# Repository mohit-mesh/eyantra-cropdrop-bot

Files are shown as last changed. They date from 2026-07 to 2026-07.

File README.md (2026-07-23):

# CropDrop Bot 🚜📦
**Autonomous Logistics System for the e-Yantra International Robotics Competition**

WhatsApp Image 2026-07-23 at 11 56 01

## 🏆 Project Overview
This repository contains the hardware designs and software stack for the "CropDrop Bot," an autonomous logistics robot. Developed for the **international e-Yantra Robotics Competition**, our system was engineered to navigate complex environments, manage payload logistics, and execute precise line-following tasks. 

Out of over 1,000 participating teams globally, our project secured a place among the **Top 20 ranked teams**.
The robot bridges low-level precision hardware with high-level autonomous decision-making. 

### Hardware Specifications
* **Microcontroller:** STM32 F103RB (ARM Cortex-M3) acting as the powerhouse for low-level execution and sensor polling.
* **Chassis & Mechanical:** Custom-modeled in Autodesk Fusion 360. The physical bot was specifically designed with a low center of gravity to ensure stability during dynamic movements and payload handling.

### Software Stack
* **Languages:** Python, C++
* **Control Systems:** We implemented a hybrid control approach using **PID controllers** combined with **Reinforcement Learning** to achieve smooth, adaptable, and highly accurate line-following behaviors under varying conditions.

## 📁 Repository Structure
```text
├── cad/                 # Fusion 360 STEP files and chassis renders
├── firmware/            # STM32 F103RB C++ source code and libraries
├── docs/                # Schematics, competition reports, and media
└── README.md

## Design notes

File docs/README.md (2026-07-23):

# 📚 Project Documentation & Media

This directory serves as the central hub for all non-code assets related to the CropDrop Bot. It includes system architecture diagrams, wiring schematics, and the progression of deliverables submitted for the e-Yantra Robotics Competition.

## 🏆 Task Progression & Video Demonstrations

The e-Yantra competition was structured as a rigorous, multi-stage evaluation. Below is the chronological breakdown of our submissions, including the specific objectives and video evidence for each stage.

### Phase 1: Simulation & Basic Control
| Task | Objective | Deliverables / Media Links |
| :--- | :--- | :--- |
| **Task 0** | Introduction to CoppeliaSim environment and basic API interactions. |
| **Task 1A** | Basic locomotion and kinematics implementation in simulation. | [Watch Video](https://youtu.be/E3lrXw1rDbM) |
| **Task 1B** | Sensor integration (vision/proximity) within the CoppeliaSim scene. | [Watch Video](https://youtu.be/_9AlKNXZCRw) |

### Phase 2: Autonomous Navigation (Simulation)
| Task | Objective | Deliverables / Media Links |
| :--- | :--- | :--- |
| **Task 2A** | Implementation of path planning algorithms in simulation. | [Watch Video](https://youtu.be/VgObchYK7ao) |
| **Task 2B** | Advanced obstacle avoidance and dynamic path replanning. | [Watch Video](https://youtu.be/pBu2Rf4UkDo) |

### Phase 3: Hardware Assembly & Setup
| Task | Objective | Deliverables / Media Links |
| :--- | :--- | :--- |
| **Task 3A** | Physical arena preparation (Flex printing and spatial calibration). | (Arena
 ) |
| **Task 3B** | Complete physical assembly of the robot (chassis, motors, sensors). | (Bot
 ) |
| **Task 3C** | Hardware-in-the-loop testing and initial motor driver calibration. | [Watch Video](https://youtube.com/shorts/ha-Rx2h62M0?feature=share) |

### Phase 4: Physical Implementation & Tuning
| Task | Objective | Deliverables / Media Links |
| :--- | :--- | :--- |
| **Task 4A** | Basic line following using IR sensor arrays (PID control). | [Watch Video](https://youtube.com/shorts/gG-tcj1-eJs?feature=share) |
| **Task 4B** | Reinforcement Learning implementation for high-speed, stable line tracking. | [Watch Video](https://youtube.com/shorts/Vpe7SxNsrb0?feature=share) |
| **Task 4C** | Integration of payload actuation (servo manipulation) with locomotion. | [Watch Video](https://youtube.com/shorts/bxdxO41b7do?feature=share) |

### Phase 5: System Integration & Optimization
| Task | Objective | Deliverables / Media Links |
| :--- | :--- | :--- |
| **Task 5A** | Establishing reliable ROS 2 to STM32 serial communication. | [Watch Video](https://youtube.com/shorts/iJJi3lMqJCQ?feature=share) |
| **Task 5B** | Integration of high-level task logic with low-level physical control. | [Watch Video](https://youtube.com/shorts/guk6uJNxQB8?feature=share) |

### Phase 6: The Grand Finale
| Task | Objective | Deliverables / Media Links |
| :--- | :--- | :--- |
| **Task 6** | **Final Theme Run:** Complete, autonomous execution of the entire logistics challenge. | [Watch Final Run Video 🌟](https://youtu.be/hnjJy23xpFI) |
| **Bonus Task** | Implementation of advanced optimizations (e.g., faster route planning and extended payload capacity) for extra points. | [Watch Bonus Run Video 🚀](https://youtu.be/7lcOlLQVplg) |

---

*Note: All corresponding source code for these tasks can be found in the respective task folders within the main repository.*

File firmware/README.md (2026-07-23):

# 💻 Firmware & Low-Level Control

This directory contains the embedded C/C++ firmware developed for the STM32 F103RB microcontroller, which acts as the low-level hardware interface for the CropDrop Bot.

The firmware is responsible for executing real-time control loops, processing raw sensor data, and safely actuating the mechanical systems based on high-level commands from the ROS 2 stack.

## ⚙️ Core Features & Capabilities

The codebase utilizes the **STM32 HAL (Hardware Abstraction Layer)** to manage the following sub-systems:

*   **Closed-Loop Locomotion:** Implements a real-time **PID control loop** for high-speed, accurate line following, utilizing fast-polling ADC reads from the IR sensor arrays.
*   **Payload Actuation:** Manages precise PWM signal generation (via hardware Timers) to control the servo motors responsible for the payload dropping mechanism.
*   **ROS 2 Serial Bridge:** Establishes robust, non-blocking UART communication to receive velocity/navigation commands from the main compute node and report back current hardware states.
*   **State Machine Architecture:** The main execution loop is structured as a non-blocking state machine, ensuring deterministic response times for critical hardware interrupts.

## 📂 Directory Structure

*   **`Core/Src/`**: Contains the main application logic (`main.c`), interrupt service routines (`stm32f1xx_it.c`), and hardware initialization functions.
*   **`Core/Inc/`**: Contains the corresponding header files.
*   **`.ioc File`**: The STM32CubeMX configuration file detailing the clock tree, pinout (GPIO, UART, I2C), and timer configurations.

> **Note to Reviewers:** The core logic, including the PID implementation and serial parsing, can be found in `Core/Src/main.c`.

## 🛠️ Build & Flash Instructions

This project is configured for use with **STM32CubeIDE**.

1.  Open **STM32CubeIDE**.
2.  Select `File` > `Open Projects from File System...`
3.  Navigate to this folder and click Finish to import the project.
4.  Click the **Build (Hammer)** icon to compile the `.elf` and `.bin` files.
5.  Connect your ST-Link to the STM32 F103RB board.
6.  Click the **Debug/Run** icon to flash the firmware directly to the microcontroller.

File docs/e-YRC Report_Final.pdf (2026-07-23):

# e-Yantra Robotics Competition 2025-26

## Technical Project Report

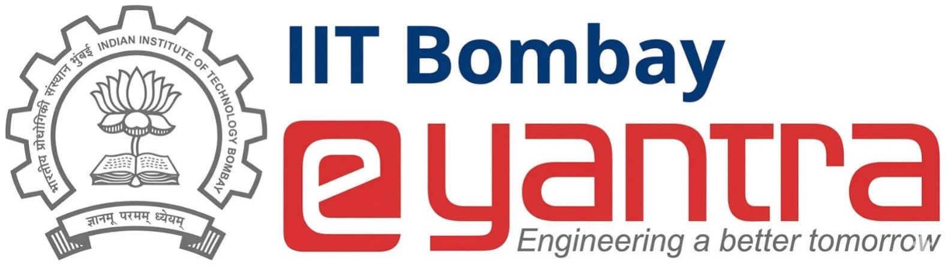
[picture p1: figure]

### Theme: Crop Drop Bot

### Institution: Zeal College of Engineering and Research

## Team Members

### Mohit (Team Lead) Sanyog Dahotre Aaryan Nikam

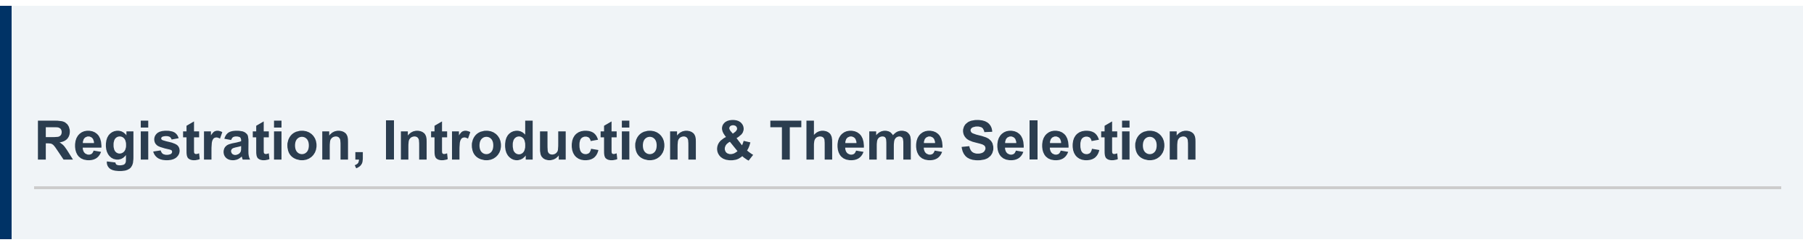
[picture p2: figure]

### 1.1 Introduction

The e-Yantra Robotics Competition (eYRC) is a flagship initiative by IIT Bombay. It provides a unique platform for engineering students to implement theory into practice through a project-based learning approach. This report documents the technical journey of the team from Zeal College of Engineering and Research in the 2025-26 edition of eYRC.

### 1.2 Team Formation

Our team was formed with a shared passion for robotics and
automation. Led by Mohit, who took on the responsibility of the
College Group Team Lead, the team comprises Sanyog Dahotre and

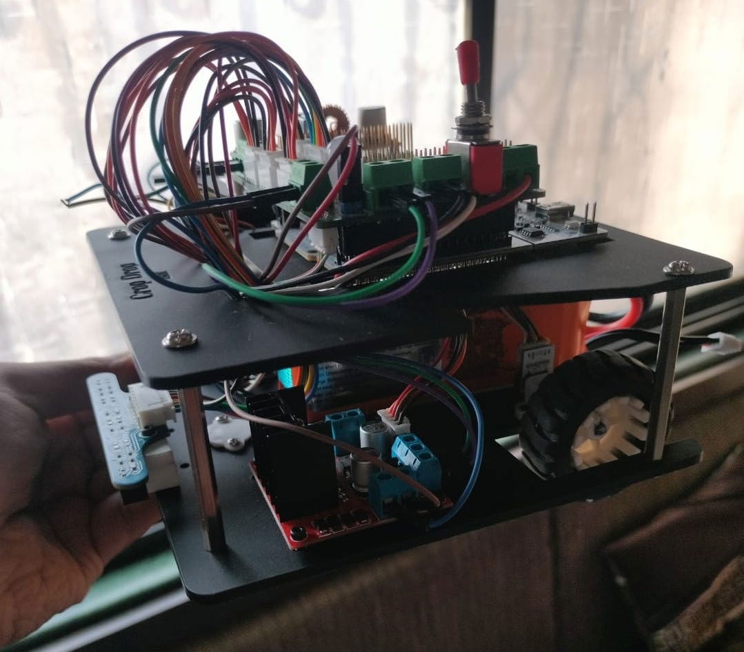
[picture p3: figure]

Aaryan Nikam. Each member brought a distinct skill set to the table, ranging from embedded systems and hardware assembly to algorithmic problem solving and simulation.

### 1.3 Theme Selection: Crop Drop Bot

Among the various themes offered in eYRC 2025-26, our team unanimously selected the "Crop Drop Bot" theme. This theme focuses on autonomous navigation and service roboticsin an agricultural context. The challenge involves designing a robot capable of traversing a greenhouse environment, identifying service zones, and performing pickand-place operations to manage crops.

We chose this theme for several strategic reasons:
Relevance: Agricultural automation is a burgeoning field with significant real-world impact. Complexity Balance: It offered a balanced mix of precision line following, complex decision-making algorithms, and mechanical manipulation.
Skill Development: It provided an opportunity to master Reinforcement Learning (RL) alongside classical control systems like PID.

Initial Strategy: Our initial approach involved dividing the project into two parallel streams: Software Simulation (handled primarily using Python and CoppeliaSim) and Hardware Research (component selection and circuit design).

## Registration, Introduction & Theme Selection

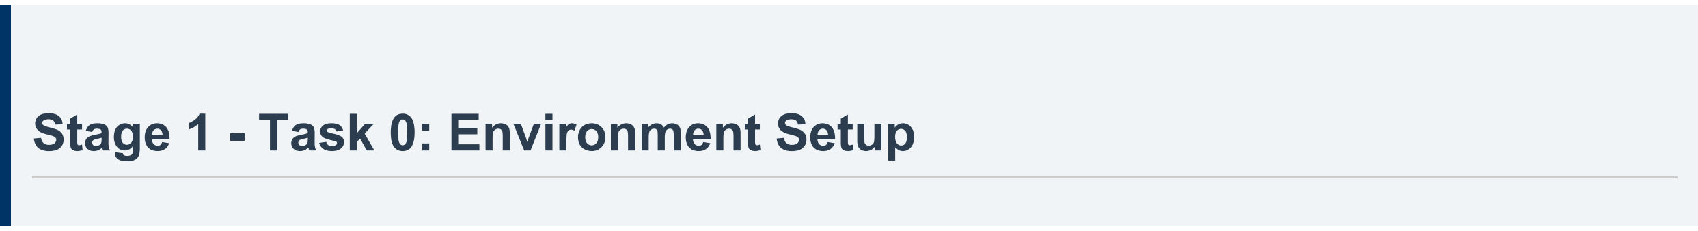
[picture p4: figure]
Stage 1 - Task 0: Environment Setup

task0_scene.ttt

### 2.1 Objective

Task 0 served as the foundational phase of the competition. The primary objective was to set up a robust development environment capable of handling complex simulations and to familiarize the team with the necessary software stack mandated by e-Yantra.

### 2.2 Software Installation

The following software tools and libraries were installed and configured:
Operating System: Ubuntu 22.04 LTS was chosen for its stability and compatibility with ROS (Robot Operating System) and robotics development tools.
CoppeliaSim (formerly V-REP): We installed CoppeliaSim Edu version. This powerful simulator was used to model the physics, sensors, and actuators of the Crop Drop Bot in a virtual environment.
Python 3.8+: The primary programming language for logic implementation.
Required Libraries:
NumPy: For numerical computations and matrix operations.
OpenCV: For image processing tasks involved in visual navigation.
PyRep/ZMQ: For interfacing Python scripts with the CoppeliaSim environment.

### 2.3 Simulation Environment Configuration

Configuring the simulation environment involved establishing a communication bridge between our Python control scripts and the CoppeliaSim scene. We utilized the Remote API provided by CoppeliaSim.

Key Steps:
1. Loaded the provided | file into CoppeliaSim.
2. Verified the port connections for the Remote API.
3. Executed a "Hello World" script to confirm that Python could send commands (e.g. motor velocity) and receive data (e.g. sensor readings) from the simulator effectively.

Outcome: By the end of Task 0, we had a fully functional simulation pipeline. We successfully verified that our codebase could control the virtual robot's motors and read data from its proximity sensors, laying the groundwork for the complex tasks ahead.

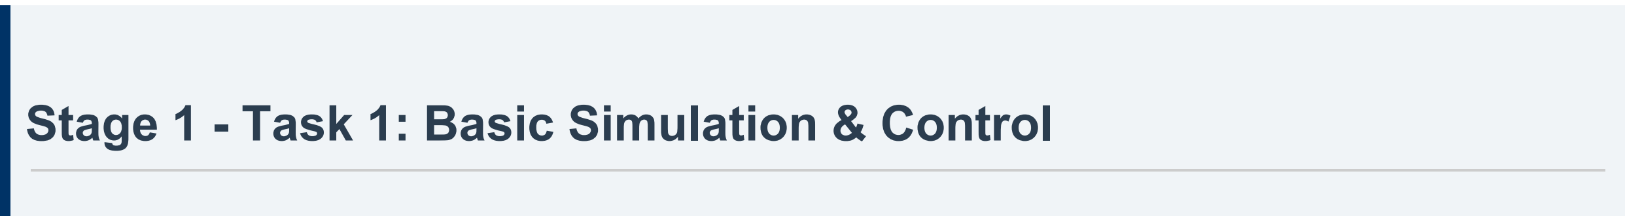
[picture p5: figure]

### 3.1 Overview

Task 1 introduced the team to the dynamics of the robot. The goal was to move the robot from a start point to a goal point within the simulation without colliding with walls. This required the implementation of control algorithms.

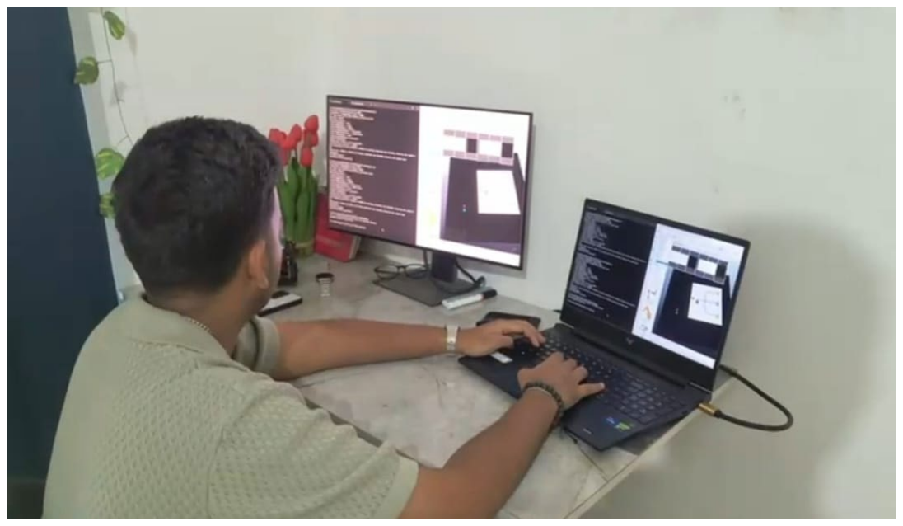
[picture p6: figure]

### 3.2 PID Controller Implementation

To ensure smooth and accurate movement, we implemented a Proportional-Integral-Derivative (PID) controller. The PID controller continuously calculated an error value as the difference between a desired setpoint (e.g., center of the lane) and a measured process variable (e.g., sensor data). Proportional (P): Provided an immediate reaction to the current error.
Integral (I): Accounted for past errors to eliminate
steady-state error.
Derivative (D): Predicted future errors based on the rate of change, providing damping to reduce overshoot.

### 3.3 Introduction to Reinforcement Learning (RL)

While PID was sufficient for line following, the competition required adaptive decision-making. We began experimenting with Q-Learning, a model-free Reinforcement Learning algorithm.

RL Setup in CoppeliaSim:
State Space: Defined by the readings from the robot's vision sensors (line position relative to center).
Action Space: Discrete actions including Move Forward, Turn Left, Turn Right.
Reward Function: The agent received positive rewards for staying on the line and negative rewards for deviating or colliding.

### 3.4 Results

The combination of PID for low-level motor control and basic RL logic for navigation allowed the bot to traverse the Task 1 arena successfully. We tuned the Kp, Ki, and Kd constants extensively to minimize oscillation, resulting in a smooth trajectory.

## Stage 1 - Task 1: Basic Simulation & Control

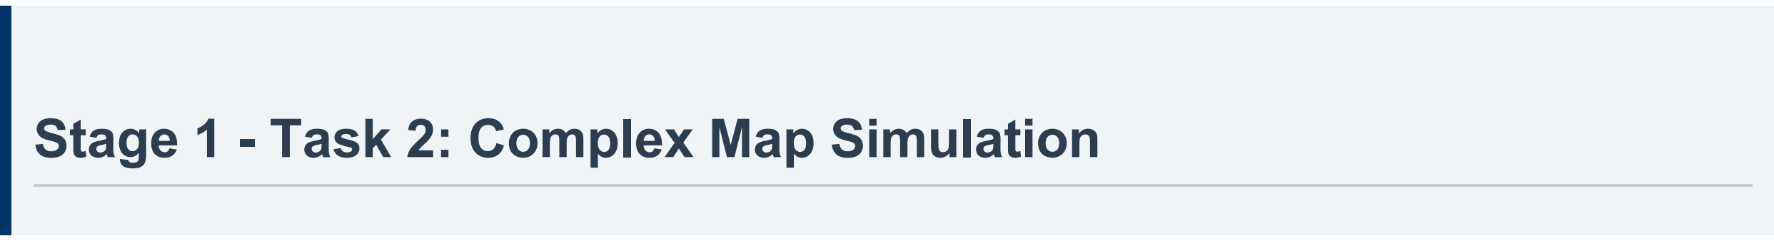
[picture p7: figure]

### 4.1 Challenge Description

Task 2 significantly increased the complexity of the simulation. The map now included sharp turns, intersections, and obstacles that mimicked the actual "Crop Drop" greenhouse environment. The robot had to navigate autonomously to specific coordinates.

### 4.2 Algorithm Modifications

The basic logic from Task 1 was insufficient for the complex geometry of Task 2. We upgraded our navigation stack to include:
Intersection Detection: We utilized array-based processing of the vision
sensor data to detect nodes
(intersections). When the sensor array

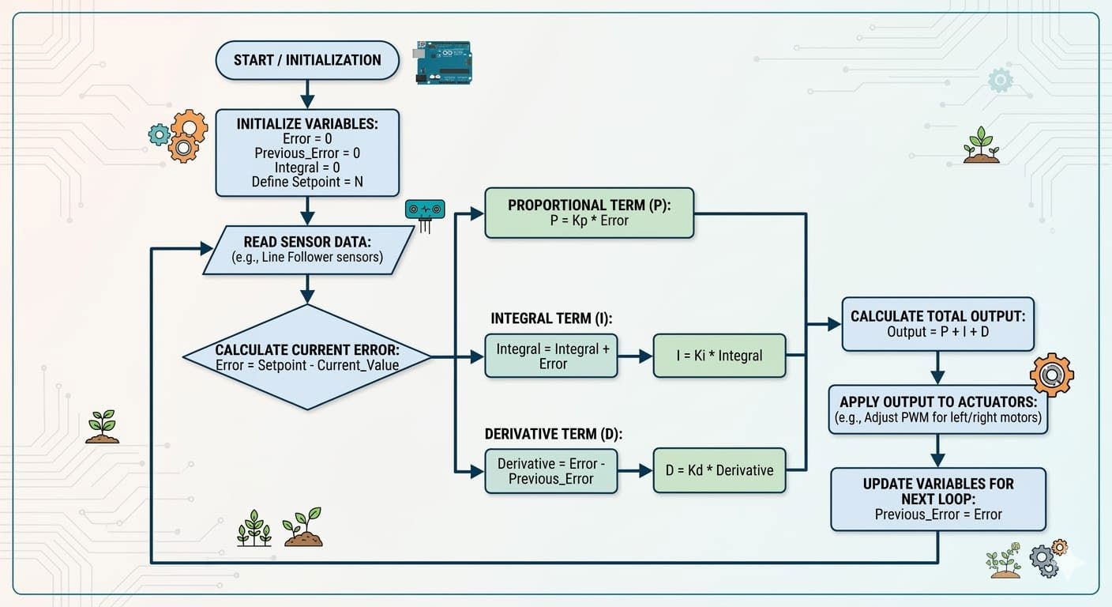
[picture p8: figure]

detected a horizontal line crossing the path, the robot identified it as a node.
Path Planning: We implemented a graph-based search algorithm (Dijkstra’s Algorithm) to determine the shortest path between the start node and the target crop zones.

### 4.3 Handling Constraints

The simulation imposed strict timing and collision constraints. To address this, we optimized our control loop: Adaptive Velocity Profiling: The robot was programmed to decelerate when approaching turns or intersections and accelerate during straight paths. This reduced the likelihood of overshooting the line during sharp maneuvers.
Sensor Noise Filtering: We applied a moving average filter to the sensor data to smooth out noise in the simulation, ensuring stable control signals.

### 4.4 Challenges & Solutions

Challenge: The robot frequently lost the line at 90-degree turns.
Solution: We implemented a "recovery mode." If the sensors detected "all white" (off-line), the robot would rotate in the direction of the last known line position until the line was re-acquired.

## Stage 1 - Task 2: Complex Map Simulation

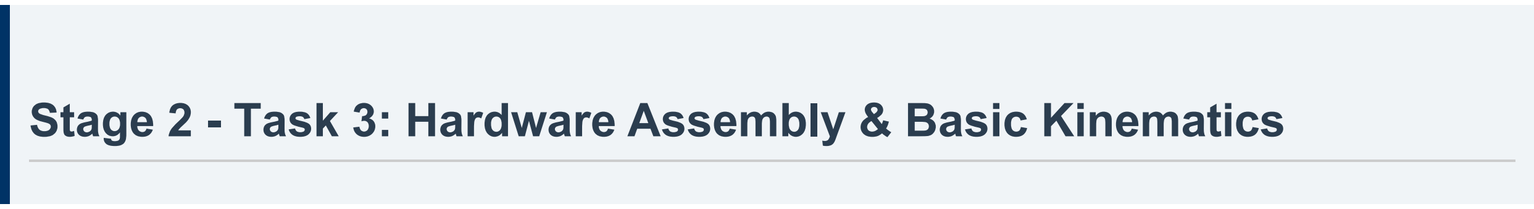
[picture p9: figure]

### 5.1 Transition to Hardware

Stage 2 marked the critical shift from virtual simulation to physical reality. Task 3 focused on assembling the "Crop Drop Bot" and validating its mechanical integrity.

### 5.2 Hardware Components

The kit provided by e-Yantra included:

Microcontroller: STM32 F103RB Actuators: N20 Metal Gear Motors with encoders for precise odometry.
Sensors: A custom-designed IR Sensor Array (5-channel) for line detection.
Power: Li-ion Battery pack (11.1V).
Chassis: Laser-cut acrylic chassis components.

### 5.3 Assembly Process

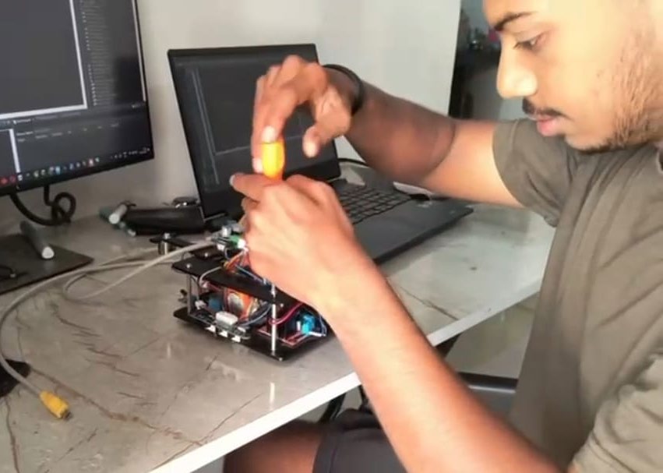
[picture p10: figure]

Mechanical Assembly: We assembled the chassis, mounting the motors and wheels in a differential drive configuration. Special attention was paid to the caster wheel to ensuring stability.

Electrical Connections: We wired the motor drivers (L298N) to the STM32 and connected the IR sensor array. We ensured proper cable management to prevent interference with moving parts.

### 5.4 Kinematics Testing

Before attempting line following, we wrote firmware to test basic kinematics:
1. Straight Line Test: Verified that both motors rotated at synchronized speeds to move the robot forward without drifting.
2. Rotational Test: Verified zero-radius turning (spinning in place) by driving motors in opposite directions.
3. Encoder Validation: We read encoder ticks to confirm that the physical distance moved matched the commanded distance.

## Stage 2 - Task 3: Hardware Assembly & Basic Kinematics

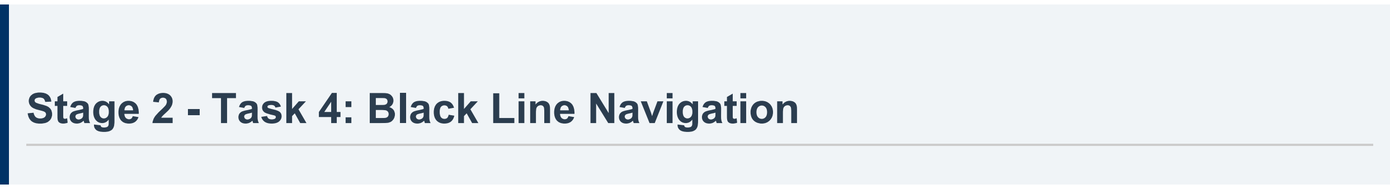
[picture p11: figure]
Stage 2 - Task 4: Black Line Navigation

### 6.1 IR Sensor Calibration

The physical environment introduces variables not present in simulation, such as ambient light and uneven surface friction. The first step in Task 4 was robust sensor calibration.

We implemented a calibration routine where the robot rotated over the line, recording the minimum (black) and maximum (white) analog values for each of the 5 sensors. These values were used to normalize readings to a 0-1000 range, ensuring consistent performance regardless of lighting changes.

### 6.2 Line Following Logic

We utilized a weighted average algorithm to determine the line's position relative to the robot's center:

This calculated position was fed into a hardware-tuned PID controller.

### 6.3 PID Tuning for Hardware

Tuning PID on hardware proved more challenging than
simulation due to physical inertia and battery voltage fluctuations.
Kp (Proportional): Increased until the robot followed the line but oscillated rapidly.
Kd (Derivative): Added to dampen the
oscillations and smooth the movement. This was
critical for high-speed tracking.

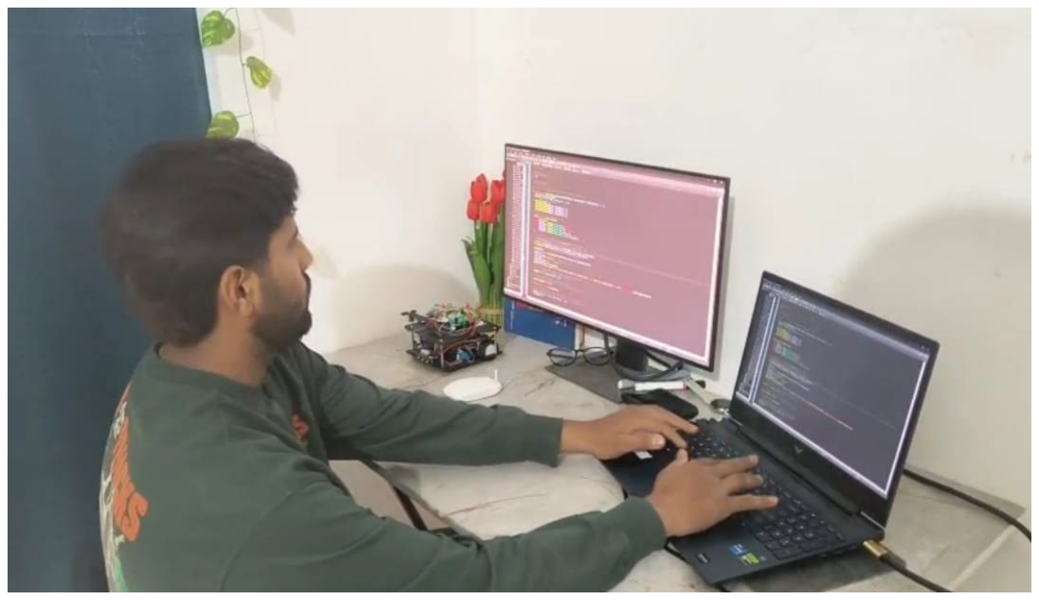
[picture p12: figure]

Ki (Integral): Kept very low to address minor drifts without causing instability.

### 6.4 Precision Movement

To handle the "stops" required at crop zones, we integrated encoder feedback. The robot could now execute commands such as "Follow line for 30cm, then stop," bridging the gap between line following and odometrybased navigation.

Position = Σ(Sensor_Value * Weight) / Σ(Sensor_Value)

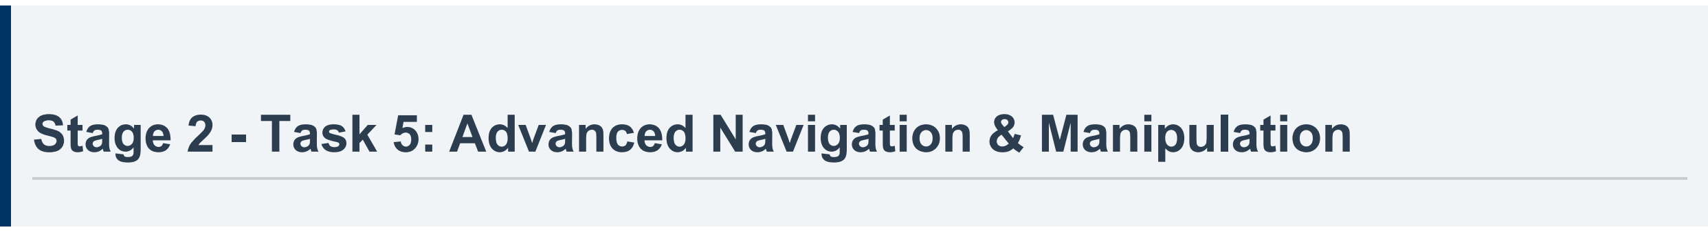
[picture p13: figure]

line_mode

### 7.1 Dual-Mode Navigation (Black vs. White Lines)

Task 5 introduced a complex arena featuring both black lines on a white background and white lines on a black background. The robot had to dynamically switch its interpretation of sensor data.

Inversion Logic: Implemented a state variable | . When the robot detected a specific marker (a
barcode-like pattern on the floor), it inverted the logic of the sensor array (treating high signals as low and viceversa) to seamlessly transition between zones.

### 7.2 Intersection Decision Making

The arena was a grid of intersections. We developed a
node-counting algorithm:
The robot counted intersections (nodes) as it traversed.
Based on a pre-loaded map array, the robot
decided whether to go straight, turn left, or
turn right at each specific node count.

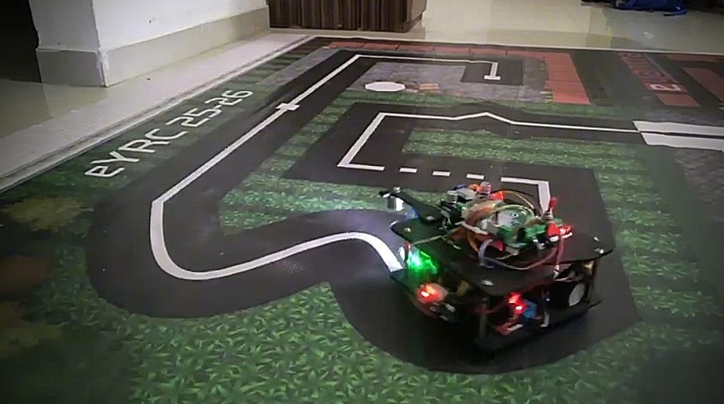
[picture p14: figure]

This determinist approach ensured the robot followed the exact required path to the crop zones.

### 7.3 Manipulation Mechanism

We designed and 3D-printed a gripper mechanism powered by a servo motor to pick up the "crop" blocks. Design: A simple electromagnetic gripper.
Integration: The gripper was mounted at the side of the chassis. The code included specific
functions | and | which adjusted the magnetic clampling action .

Alignment: Accurate stopping was crucial. We fine-tuned the braking logic to ensure the gripper was perfectly aligned with the crop block when the robot stopped.

## Stage 2 - Task 5: Advanced Navigation & Manipulation

pick_crop() place_crop()

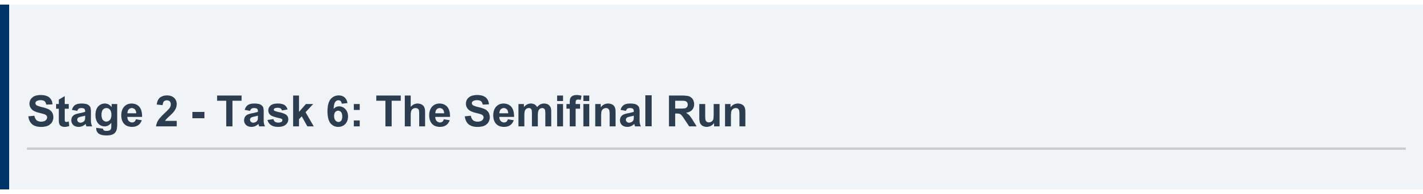
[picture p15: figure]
Stage 2 - Task 6: The Semifinal Run

### 8.1 The Semifinal Challenge

Task 6 was the culmination of our efforts. It required a complete, autonomous run on the full physical arena. The robot had to: 1. Start from the depot. 2. Navigate to multiple crop zones. 3. Pick up crops. 4. Transport them to specific drop zones based on color codes. 5. Return to the start point.

### 8.2 Integrated Run Execution

The final code merged the navigation stack, the
manipulation logic, and the path planning algorithms into a single robust state machine.

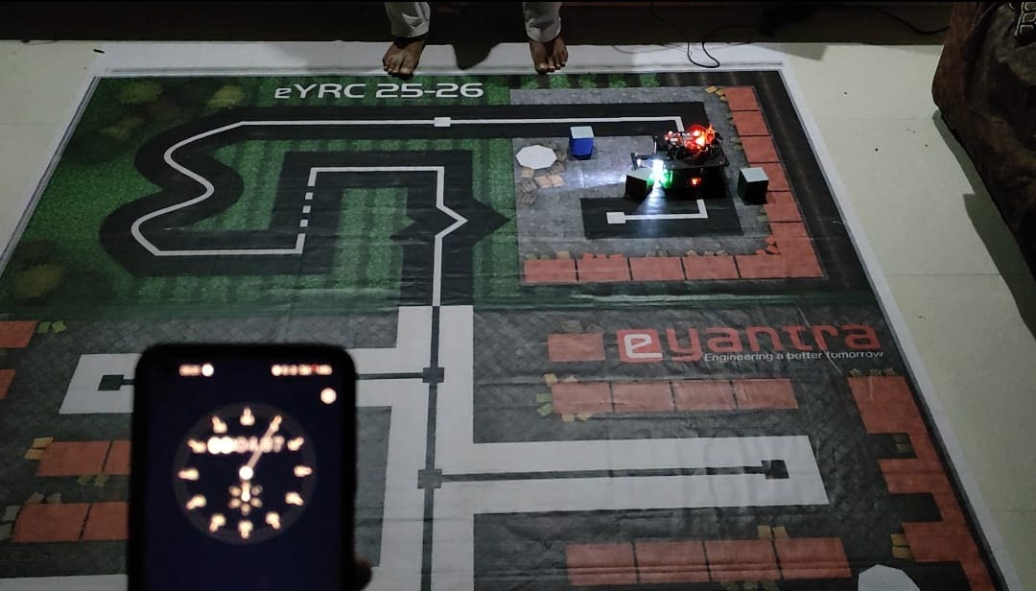
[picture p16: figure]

Performance:
During the semifinal video submission, our Crop Drop Bot successfully navigated the arena. It demonstrated precise line switching (Black to White) and accurate intersection turning. The gripper mechanism successfully picked up the designated crops.

### 8.3 Challenges Faced

Despite our success, we faced significant challenges:
Lighting Sensitivity: The semifinal arena had varying lighting conditions which initially caused false triggers on the sensors. We resolved this by implementing dynamic thresholding in the software.
Power Drain: The voltage drop during motor operation occasionally reset the microcontroller. We added a large capacitor across the power rails to buffer these spikes.

### 8.4 Result

We completed the run with high accuracy. While we did not advance to the finals based on timing metrics, our technical implementation was highly rated, leading to further opportunities with IIT Bombay.

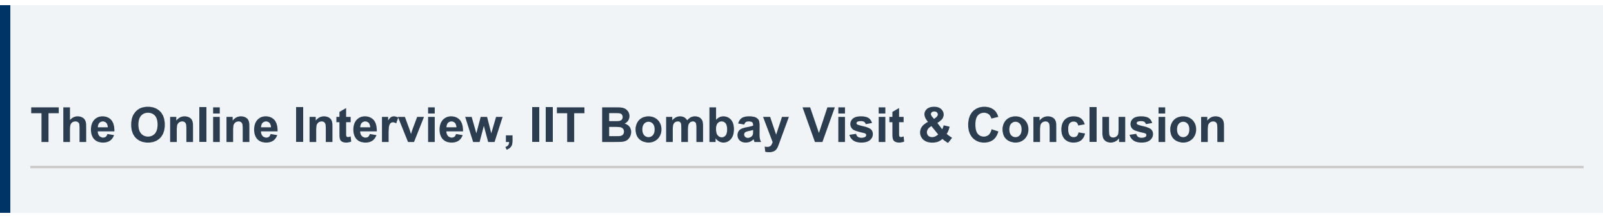
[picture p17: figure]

### 9.1 Internship Interview

Based on our strong performance in the semifinals, our team was shortlisted for an internship interview with the e-Yantra labs at IIT Bombay.

The interview was a rigorous technical assessment conducted online by IIT Bombay mentors. We defended our code logic, explained our choice of PID constants, and discussed the intricacies of our sensor calibration routine. The panel tested our understanding of:
Embedded C programming nuances.
Algorithm efficiency (Big O notation of our path planning).
Electrical circuit isolation and motor driver characteristics.

(Results of this interview are currently pending.)

### 9.2 Invitation to IIT Bombay

We have received an official invitation to visit the IIT Bombay campus as guests during the finals. This visit serves three purposes:
1. Observation: To witness the Grand Finale and learn from the top competing teams.
2. Hardware Return: To officially return the robotic components provided for the competition.
3. Certification: To collect our certificates of completion and merit in person.

### 9.3 Skills Acquired

Technical Skills:
We have gained proficiency in CoppeliaSim for simulation, Python & Embedded C for control logic, and PID Control systems. We also gained practical experience in Reinforcement Learning basics and hardware debugging.

Soft Skills:
The journey honed our teamwork, crisis management (debugging hardware hours before deadlines), and technical documentation skills.

### 9.4 Conclusion

Participating in eYRC 2025-26 has been a transformative experience for the team from Zeal College of Engineering and Research. While we stopped at the semifinals, the knowledge gained and the recognition received from IIT Bombay have set a strong foundation for our future careers in robotics and automation.

## The Online Interview, IIT Bombay Visit & Conclusion

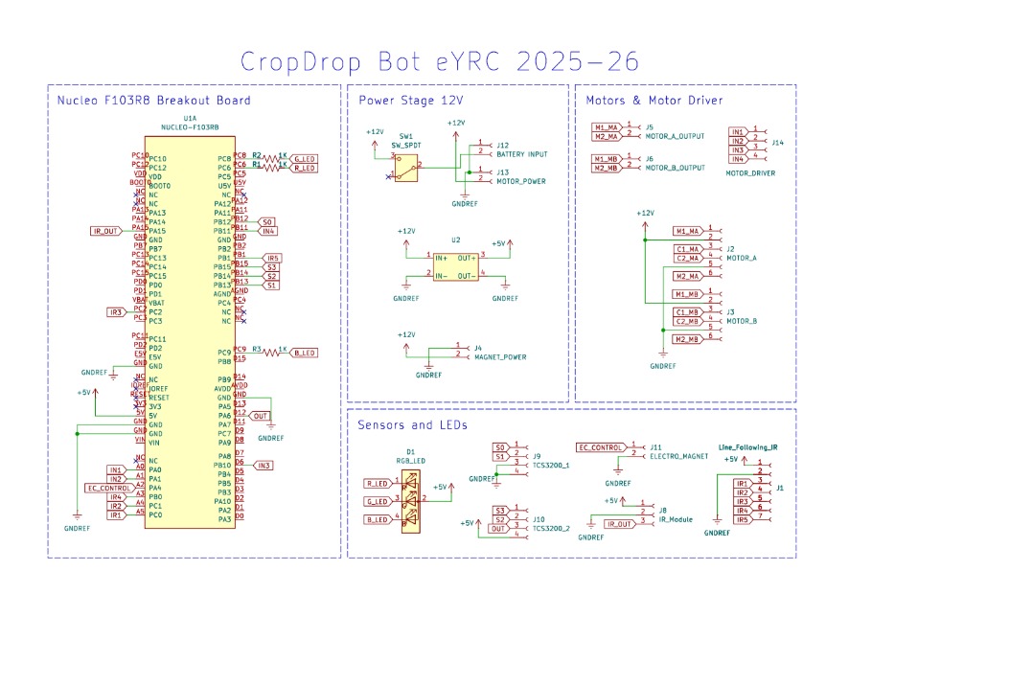
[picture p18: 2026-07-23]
docs/schematic/e-YRC Schematic.jpeg

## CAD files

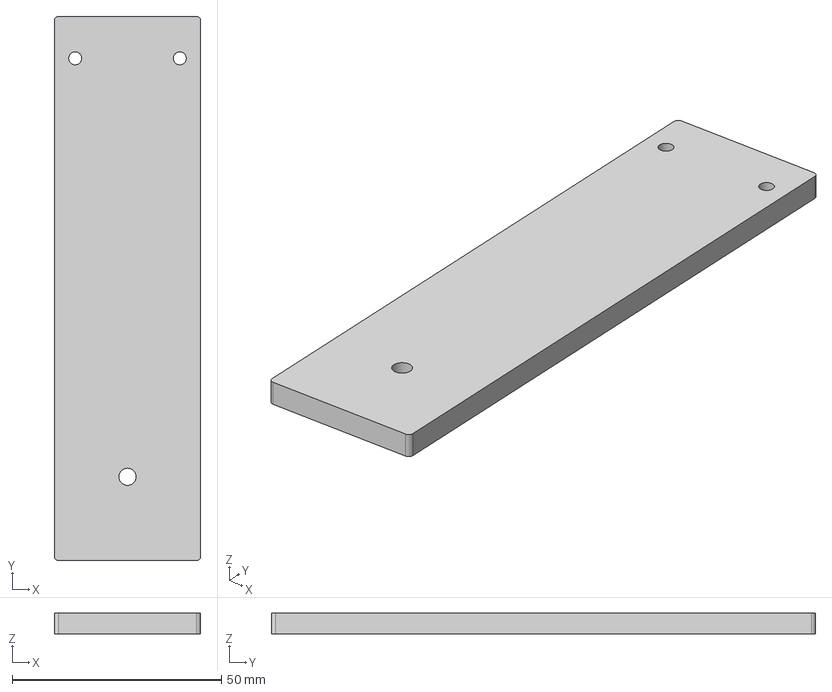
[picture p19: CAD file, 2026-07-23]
cad/electromagnet_holder.step
35.0 x 130.0 x 5.00 mm

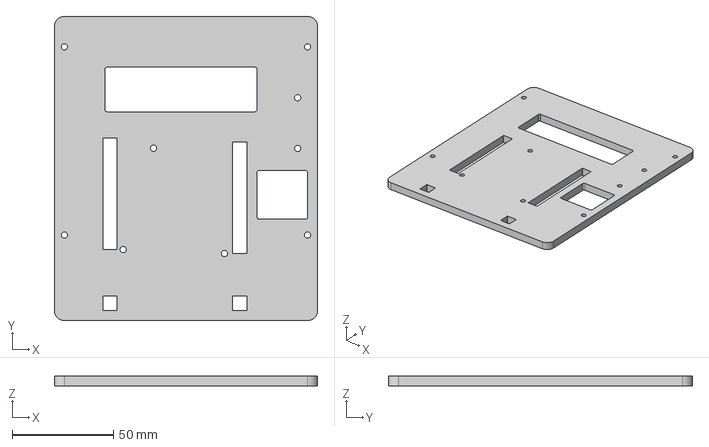
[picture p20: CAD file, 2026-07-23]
cad/Upper_Plate.step
130.0 x 150.0 x 5.00 mm

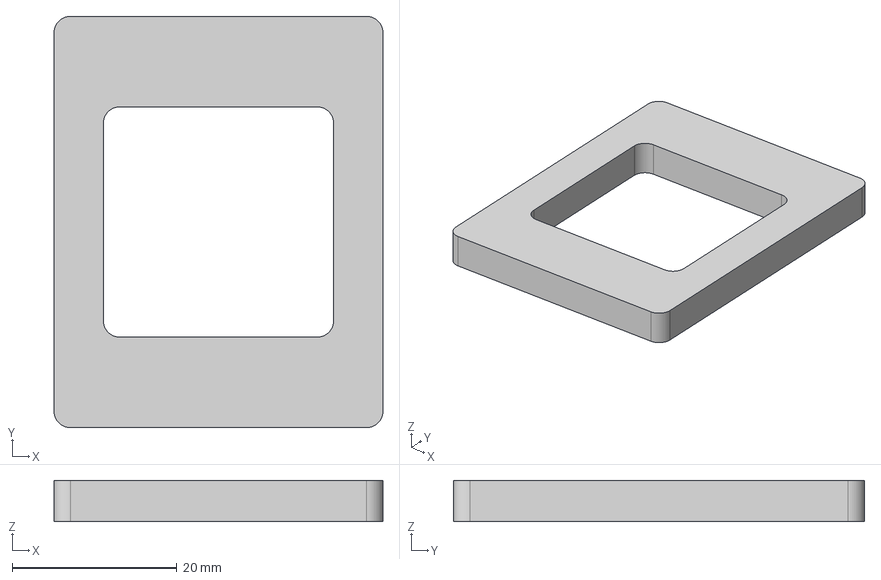
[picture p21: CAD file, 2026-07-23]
cad/coloursensor_holder.step
40.0 x 50.0 x 5.00 mm

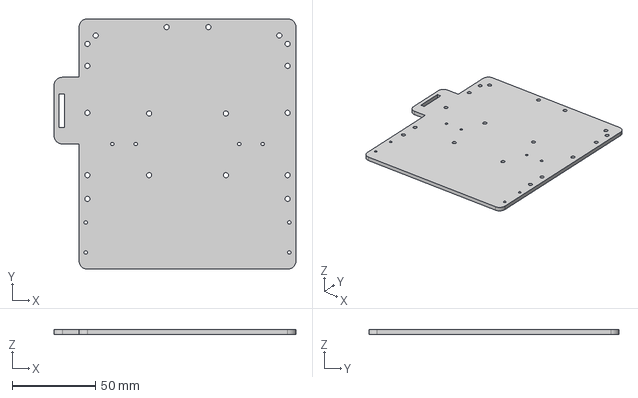
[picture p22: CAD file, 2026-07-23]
cad/Base_Plate.step
145.0 x 150.0 x 3.00 mm

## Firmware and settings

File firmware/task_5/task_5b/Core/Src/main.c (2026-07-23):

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
/* Includes ------------------------------------------------------------------*/
#include "main.h"
#include "Box_Handling.h"

/* USER CODE BEGIN Includes */
#include <math.h>
#include <stdlib.h>
#include <stdio.h>
/* USER CODE END Includes */

/* USER CODE BEGIN PD */
#define NUM_SENSORS 5

// --- TUNING PARAMETERS ---
#define KP 35.0f
#define KD 100.0f
#define BASE_SPEED 100
#define MAX_PWM 200
#define TURN_SPEED 90

// LOGIC THRESHOLDS
// If Average Sensor Value > 2500, we assume White Floor (High values)
#define FLOOR_COLOR_THRESHOLD 2500

/* USER CODE END PD */

ADC_HandleTypeDef hadc1;
DMA_HandleTypeDef hdma_adc1;

TIM_HandleTypeDef htim2;
TIM_HandleTypeDef htim3;

UART_HandleTypeDef huart2;

/* USER CODE BEGIN PV */
volatile uint16_t adc_buffer[NUM_SENSORS];

// Normalized Line Position (0-1000) for each sensor
float line_map[NUM_SENSORS];

// Weights: Left ... Center ... Right
const float sensor_weights[NUM_SENSORS] = {-2.0f, -1.0f, 0.0f, 1.0f, 2.0f};

/* USER CODE END PV */

void SystemClock_Config(void);
static void MX_GPIO_Init(void);
static void MX_DMA_Init(void);
static void MX_USART2_UART_Init(void);
static void MX_ADC1_Init(void);
static void MX_TIM2_Init(void);
static void MX_TIM3_Init(void);
/* USER CODE BEGIN PFP */
void Motor_SetSpeed(int left, int right);
void Handle_Turn(int direction);
void Calibrate_Sensors(void); // Keeping prototype but calibration is dynamic now
/* USER CODE END PFP */

/* USER CODE BEGIN 0 */

void Motor_SetSpeed(int left, int right) {
  if (left > 255) left = 255; else if (left < -255) left = -255;
  if (right > 255) right = 255; else if (right < -255) right = -255;

  if (left >= 0) {
    __HAL_TIM_SET_COMPARE(&htim2, TIM_CHANNEL_1, left);
    __HAL_TIM_SET_COMPARE(&htim2, TIM_CHANNEL_2, 0);
  } else {
    __HAL_TIM_SET_COMPARE(&htim2, TIM_CHANNEL_1, 0);
    __HAL_TIM_SET_COMPARE(&htim2, TIM_CHANNEL_2, -left);
  }

  if (right >= 0) {
    __HAL_TIM_SET_COMPARE(&htim2, TIM_CHANNEL_3, right);
    __HAL_TIM_SET_COMPARE(&htim2, TIM_CHANNEL_4, 0);
  } else {
    __HAL_TIM_SET_COMPARE(&htim2, TIM_CHANNEL_3, 0);
    __HAL_TIM_SET_COMPARE(&htim2, TIM_CHANNEL_4, -right);
  }
}

// Robust Turn Function using Dynamic Detection
void Handle_Turn(int direction) {
    // 1. Stop
    Motor_SetSpeed(0, 0);
    HAL_Delay(100);

    // 2. Move Forward slightly
    Motor_SetSpeed(80, 80);
    HAL_Delay(250);

    // 3. Start Spin
    int spd_L = (direction == -1) ? -TURN_SPEED : TURN_SPEED;
    int spd_R = (direction == -1) ? TURN_SPEED : -TURN_SPEED;
    Motor_SetSpeed(spd_L, spd_R);
    HAL_Delay(300); // Blind spin

    // 4. Wait for Line
    uint32_t start_time = HAL_GetTick();
    while (HAL_GetTick() - start_time < 2000) { // 2s Timeout
        // Determine Contrast
        long sum = 0;
        for(int i=0; i<NUM_SENSORS; i++) sum += adc_buffer[i];
        long avg = sum / NUM_SENSORS;

        int center_val = adc_buffer[2];
        int on_line = 0;

        // Dynamic Threshold Check
        if (avg > FLOOR_COLOR_THRESHOLD) {
             // White Floor: Line is Low (Dark)
             if (center_val < (avg - 600)) on_line = 1;
        } else {
             // Black Floor: Line is High (White)
             if (center_val > (avg + 600)) on_line = 1;
        }

        if (on_line) {
            Motor_SetSpeed(0, 0);
            return;
        }

        HAL_Delay(5);
    }
    // Timeout - Stop
    Motor_SetSpeed(0, 0);
}

void Calibrate_Sensors(void) {
    // Legacy support: Just blink to show readiness
    // Since we use dynamic contrast, we don't need MIN/MAX arrays hardcoded.
    HAL_GPIO_WritePin(GPIOC, RED_Pin, GPIO_PIN_SET);
    HAL_Delay(500);
    HAL_GPIO_WritePin(GPIOC, RED_Pin, GPIO_PIN_RESET);
}

/* USER CODE END 0 */

/**
  * @brief  The application entry point.
  * @retval int
  */
int main(void)
{
  /* MCU Configuration--------------------------------------------------------*/
  HAL_Init();

  SystemClock_Config();

  /* Initialize all configured peripherals */
  MX_GPIO_Init();
  MX_DMA_Init();
  MX_USART2_UART_Init();
  MX_ADC1_Init();
  MX_TIM2_Init();
  MX_TIM3_Init();
  /* USER CODE BEGIN 2 */

  HAL_TIM_PWM_Start(&htim2, TIM_CHANNEL_1);
  HAL_TIM_PWM_Start(&htim2, TIM_CHANNEL_2);
  HAL_TIM_PWM_Start(&htim2, TIM_CHANNEL_3);
  HAL_TIM_PWM_Start(&htim2, TIM_CHANNEL_4);

  HAL_ADC_Start_DMA(&hadc1, (uint32_t*)adc_buffer, NUM_SENSORS);

  // Wait to start
  HAL_Delay(1000);
  Calibrate_Sensors();

  /* Initialize Box Handling (Color Sensor + Electromagnet) */
  Box_Init(&htim3);

  float last_error = 0;

  /* USER CODE END 2 */

  /* Infinite loop */
  /* USER CODE BEGIN WHILE */
  while (1)
  {
    /* USER CODE END WHILE */

    /* USER CODE BEGIN 3 */

    // --- 1. SENSOR ANALYSIS ---
    long total_raw = 0;
    uint16_t max_val = 0;
    uint16_t min_val = 4096;

    for(int i=0; i<NUM_SENSORS; i++) {
        total_raw += adc_buffer[i];
        if (adc_buffer[i] > max_val) max_val = adc_buffer[i];
        if (adc_buffer[i] < min_val) min_val = adc_buffer[i];
    }
    long avg_raw = total_raw / NUM_SENSORS;

    // --- 2. DYNAMICAL NORMALIZATION ---
    // Detect Floor Color
    int white_floor = (avg_raw > FLOOR_COLOR_THRESHOLD);

    float weighted_sum = 0;
    float total_line_val = 0;

    for(int i=0; i<NUM_SENSORS; i++) {
        float val;

        if (white_floor) {
            // WHITE FLOOR (BackgroundHigh, LineLow)
            // Signal = (Background - Sensor)
            // Use local max as baseline for background to be robust
            if (max_val < 3800) max_val = 4095;

            val = (float)(max_val - adc_buffer[i]);
            if (val < 0) val = 0;
        } else {
            // BLACK FLOOR (BackgroundLow, LineHigh)
            // Signal = (Sensor - Background)
             // Use local min as baseline
            val = (float)(adc_buffer[i] - min_val);
            if (val < 0) val = 0;
        }

        line_map[i] = val;

        // Accumulate if signal is significant (> 300 to filter noise)
        if (val > 400.0f) {
            weighted_sum += val * sensor_weights[i];
            total_line_val += val;
        }
    }

    // --- 3. TURN DETECTION ---
    // If Edge Sensors are strongly triggered relative to center
    // Check normalized values strength (>700 is strong contrast)
    int turn_detected = 0;

    // Robust check: S0 is Strong AND triggers logic
    if (line_map[0] > 700 && line_map[0] > line_map[2] * 1.5) {
         Handle_Turn(-1);
         turn_detected = 1;
    }
    else if (line_map[4] > 700 && line_map[4] > line_map[2] * 1.5) {
         Handle_Turn(1);
         turn_detected = 1;
    }

    if (turn_detected) {
        last_error = 0;
        continue;
    }

    // --- 4. PID CALCULATION ---
    float position;
    if (total_line_val > 500) {
        position = weighted_sum / total_line_val;
    } else {
        // Line Lost -> Use last error to sweep
        if (last_error > 0) position = 2.5f;
        else position = -2.5f;
    }

    float error = position;
    float P = error;
    float D = error - last_error;
    last_error = error;

    float correction = (KP * P) + (KD * D);

    int left_motor = BASE_SPEED + (int)correction;
    int right_motor = BASE_SPEED - (int)correction;

    Motor_SetSpeed(left_motor, right_motor);

    /* Box Handling Process (Keep running this) */
    Box_Process();

    HAL_Delay(1);
  }
  /* USER CODE END 3 */
}
//...
// (Previous MX Functions follow, identical to before)
//...
void SystemClock_Config(void)
{
  RCC_OscInitTypeDef RCC_OscInitStruct = {0};
  RCC_ClkInitTypeDef RCC_ClkInitStruct = {0};
  RCC_PeriphCLKInitTypeDef PeriphClkInit = {0};
  RCC_OscInitStruct.OscillatorType = RCC_OSCILLATORTYPE_HSE;
  RCC_OscInitStruct.HSEState = RCC_HSE_BYPASS;
  RCC_OscInitStruct.HSEPredivValue = RCC_HSE_PREDIV_DIV1;
  RCC_OscInitStruct.HSIState = RCC_HSI_ON;
  RCC_OscInitStruct.PLL.PLLState = RCC_PLL_ON;
  RCC_OscInitStruct.PLL.PLLSource = RCC_PLLSOURCE_HSE;
  RCC_OscInitStruct.PLL.PLLMUL = RCC_PLL_MUL9;
  if (HAL_RCC_OscConfig(&RCC_OscInitStruct) != HAL_OK) Error_Handler();
  RCC_ClkInitStruct.ClockType = RCC_CLOCKTYPE_HCLK|RCC_CLOCKTYPE_SYSCLK|RCC_CLOCKTYPE_PCLK1|RCC_CLOCKTYPE_PCLK2;
  RCC_ClkInitStruct.SYSCLKSource = RCC_SYSCLKSOURCE_PLLCLK;
  RCC_ClkInitStruct.AHBCLKDivider = RCC_SYSCLK_DIV1;
  RCC_ClkInitStruct.APB1CLKDivider = RCC_HCLK_DIV2;
  RCC_ClkInitStruct.APB2CLKDivider = RCC_HCLK_DIV1;
  if (HAL_RCC_ClockConfig(&RCC_ClkInitStruct, FLASH_LATENCY_2) != HAL_OK) Error_Handler();
  PeriphClkInit.PeriphClockSelection = RCC_PERIPHCLK_ADC;
  PeriphClkInit.AdcClockSelection = RCC_ADCPCLK2_DIV6;
  if (HAL_RCCEx_PeriphCLKConfig(&PeriphClkInit) != HAL_OK) Error_Handler();
}

static void MX_ADC1_Init(void)
{
  ADC_ChannelConfTypeDef sConfig = {0};
  hadc1.Instance = ADC1;
  hadc1.Init.ScanConvMode = ADC_SCAN_ENABLE;
  hadc1.Init.ContinuousConvMode = ENABLE;
  hadc1.Init.DiscontinuousConvMode = DISABLE;
  hadc1.Init.ExternalTrigConv = ADC_SOFTWARE_START;
  hadc1.Init.DataAlign = ADC_DATAALIGN_RIGHT;
  hadc1.Init.NbrOfConversion = 5;
  if (HAL_ADC_Init(&hadc1) != HAL_OK) Error_Handler();
  sConfig.Channel = ADC_CHANNEL_10; sConfig.Rank = ADC_REGULAR_RANK_1; sConfig.SamplingTime = ADC_SAMPLETIME_55CYCLES_5;
  if (HAL_ADC_ConfigChannel(&hadc1, &sConfig) != HAL_OK) Error_Handler();
  sConfig.Channel = ADC_CHANNEL_11; sConfig.Rank = ADC_REGULAR_RANK_2;
  if (HAL_ADC_ConfigChannel(&hadc1, &sConfig) != HAL_OK) Error_Handler();
  sConfig.Channel = ADC_CHANNEL_12; sConfig.Rank = ADC_REGULAR_RANK_3;
  if (HAL_ADC_ConfigChannel(&hadc1, &sConfig) != HAL_OK) Error_Handler();
  sConfig.Channel = ADC_CHANNEL_8; sConfig.Rank = ADC_REGULAR_RANK_4;
  if (HAL_ADC_ConfigChannel(&hadc1, &sConfig) != HAL_OK) Error_Handler();
  sConfig.Channel = ADC_CHANNEL_9; sConfig.Rank = ADC_REGULAR_RANK_5;
  if (HAL_ADC_ConfigChannel(&hadc1, &sConfig) != HAL_OK) Error_Handler();
}

static void MX_TIM2_Init(void)
{
  TIM_MasterConfigTypeDef sMasterConfig = {0};
  TIM_OC_InitTypeDef sConfigOC = {0};
  htim2.Instance = TIM2;
  htim2.Init.Prescaler = 72-1;
  htim2.Init.CounterMode = TIM_COUNTERMODE_UP;
  htim2.Init.Period = 255;
  htim2.Init.ClockDivision = TIM_CLOCKDIVISION_DIV1;
  htim2.Init.AutoReloadPreload = TIM_AUTORELOAD_PRELOAD_DISABLE;
  if (HAL_TIM_PWM_Init(&htim2) != HAL_OK) Error_Handler();
  sMasterConfig.MasterOutputTrigger = TIM_TRGO_RESET;
  sMasterConfig.MasterSlaveMode = TIM_MASTERSLAVEMODE_DISABLE;
  if (HAL_TIMEx_MasterConfigSynchronization(&htim2, &sMasterConfig) != HAL_OK) Error_Handler();
  sConfigOC.OCMode = TIM_OCMODE_PWM1;
  sConfigOC.Pulse = 0;
  sConfigOC.OCPolarity = TIM_OCPOLARITY_HIGH;
  sConfigOC.OCFastMode = TIM_OCFAST_DISABLE;
  HAL_TIM_PWM_ConfigChannel(&htim2, &sConfigOC, TIM_CHANNEL_1);
  HAL_TIM_PWM_ConfigChannel(&htim2, &sConfigOC, TIM_CHANNEL_2);
  HAL_TIM_PWM_ConfigChannel(&htim2, &sConfigOC, TIM_CHANNEL_3);
  HAL_TIM_PWM_ConfigChannel(&htim2, &sConfigOC, TIM_CHANNEL_4);
  HAL_TIM_MspPostInit(&htim2);
}

static void MX_TIM3_Init(void)
{
  TIM_MasterConfigTypeDef sMasterConfig = {0};
  TIM_IC_InitTypeDef sConfigIC = {0};
  htim3.Instance = TIM3;
  htim3.Init.Prescaler = 0;
  htim3.Init.CounterMode = TIM_COUNTERMODE_UP;
  htim3.Init.Period = 65535;
  htim3.Init.ClockDivision = TIM_CLOCKDIVISION_DIV1;
  htim3.Init.AutoReloadPreload = TIM_AUTORELOAD_PRELOAD_DISABLE;
  if (HAL_TIM_IC_Init(&htim3) != HAL_OK) Error_Handler();
  sMasterConfig.MasterOutputTrigger = TIM_TRGO_RESET;
  sMasterConfig.MasterSlaveMode = TIM_MASTERSLAVEMODE_DISABLE;
  if (HAL_TIMEx_MasterConfigSynchronization(&htim3, &sMasterConfig) != HAL_OK) Error_Handler();
  sConfigIC.ICPolarity = TIM_INPUTCHANNELPOLARITY_RISING;
  sConfigIC.ICSelection = TIM_ICSELECTION_DIRECTTI;
  sConfigIC.ICPrescaler = TIM_ICPSC_DIV1;
  sConfigIC.ICFilter = 0;
  HAL_TIM_IC_ConfigChannel(&htim3, &sConfigIC, TIM_CHANNEL_1);
}

static void MX_USART2_UART_Init(void)
{
  huart2.Instance = USART2;
  huart2.Init.BaudRate = 115200;
  huart2.Init.WordLength = UART_WORDLENGTH_8B;
  huart2.Init.StopBits = UART_STOPBITS_1;
  huart2.Init.Parity = UART_PARITY_NONE;
  huart2.Init.Mode = UART_MODE_TX_RX;
  huart2.Init.HwFlowCtl = UART_HWCONTROL_NONE;
  huart2.Init.OverSampling = UART_OVERSAMPLING_16;
  HAL_UART_Init(&huart2);
}

static void MX_DMA_Init(void)
{
  __HAL_RCC_DMA1_CLK_ENABLE();
  HAL_NVIC_SetPriority(DMA1_Channel1_IRQn, 0, 0);
  HAL_NVIC_EnableIRQ(DMA1_Channel1_IRQn);
}

static void MX_GPIO_Init(void)
{
  GPIO_InitTypeDef GPIO_InitStruct = {0};
  __HAL_RCC_GPIOC_CLK_ENABLE();
  __HAL_RCC_GPIOD_CLK_ENABLE();
  __HAL_RCC_GPIOA_CLK_ENABLE();
  __HAL_RCC_GPIOB_CLK_ENABLE();
  HAL_GPIO_WritePin(GPIOA, Electromagnet_Pin|LD2_Pin, GPIO_PIN_RESET);
  HAL_GPIO_WritePin(GPIOB, S0_Pin|S1_Pin|S2_Pin|S3_Pin, GPIO_PIN_RESET);
  HAL_GPIO_WritePin(GPIOC, RED_Pin|GREEN_Pin|BLUE_Pin, GPIO_PIN_RESET);
  GPIO_InitStruct.Pin = B1_Pin;
  GPIO_InitStruct.Mode = GPIO_MODE_IT_RISING;
  GPIO_InitStruct.Pull = GPIO_NOPULL;
  HAL_GPIO_Init(B1_GPIO_Port, &GPIO_InitStruct);
  GPIO_InitStruct.Pin = Electromagnet_Pin|LD2_Pin;
  GPIO_InitStruct.Mode = GPIO_MODE_OUTPUT_PP;
  GPIO_InitStruct.Pull = GPIO_NOPULL;
  GPIO_InitStruct.Speed = GPIO_SPEED_FREQ_LOW;
  HAL_GPIO_Init(GPIOA, &GPIO_InitStruct);
  GPIO_InitStruct.Pin = S0_Pin|S1_Pin|S2_Pin|S3_Pin;
  GPIO_InitStruct.Mode = GPIO_MODE_OUTPUT_PP;
  GPIO_InitStruct.Pull = GPIO_NOPULL;
  GPIO_InitStruct.Speed = GPIO_SPEED_FREQ_LOW;
  HAL_GPIO_Init(GPIOB, &GPIO_InitStruct);
  GPIO_InitStruct.Pin = RED_Pin|GREEN_Pin|BLUE_Pin;
  GPIO_InitStruct.Mode = GPIO_MODE_OUTPUT_PP;
  GPIO_InitStruct.Pull = GPIO_NOPULL;
  GPIO_InitStruct.Speed = GPIO_SPEED_FREQ_LOW;
  HAL_GPIO_Init(GPIOC, &GPIO_InitStruct);
  GPIO_InitStruct.Pin = Box_detect_Pin;
  GPIO_InitStruct.Mode = GPIO_MODE_INPUT;
  GPIO_InitStruct.Pull = GPIO_NOPULL;
  HAL_GPIO_Init(Box_detect_GPIO_Port, &GPIO_InitStruct);
  HAL_NVIC_SetPriority(EXTI15_10_IRQn, 0, 0);
  HAL_NVIC_EnableIRQ(EXTI15_10_IRQn);
}

void Error_Handler(void)
{
  __disable_irq();
  while (1) { }
}

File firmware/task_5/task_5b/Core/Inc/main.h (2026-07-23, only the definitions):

#define B1_Pin GPIO_PIN_13
#define B1_GPIO_Port GPIOC
#define B1_EXTI_IRQn EXTI15_10_IRQn
#define IR1_Pin GPIO_PIN_0
#define IR1_GPIO_Port GPIOC
#define IR2_Pin GPIO_PIN_1
#define IR2_GPIO_Port GPIOC
#define IR3_Pin GPIO_PIN_2
#define IR3_GPIO_Port GPIOC
#define IN1_Pin GPIO_PIN_0
#define IN1_GPIO_Port GPIOA
#define IN2_Pin GPIO_PIN_1
#define IN2_GPIO_Port GPIOA
#define USART_TX_Pin GPIO_PIN_2
#define USART_TX_GPIO_Port GPIOA
#define USART_RX_Pin GPIO_PIN_3
#define USART_RX_GPIO_Port GPIOA
#define Electromagnet_Pin GPIO_PIN_4
#define Electromagnet_GPIO_Port GPIOA
#define LD2_Pin GPIO_PIN_5
#define LD2_GPIO_Port GPIOA
#define Color_out_Pin GPIO_PIN_6
#define Color_out_GPIO_Port GPIOA
#define IR4_Pin GPIO_PIN_0
#define IR4_GPIO_Port GPIOB
#define IR5_Pin GPIO_PIN_1
#define IR5_GPIO_Port GPIOB
#define In3_Pin GPIO_PIN_10
#define In3_GPIO_Port GPIOB
#define IN4_Pin GPIO_PIN_11
#define IN4_GPIO_Port GPIOB
#define S0_Pin GPIO_PIN_12
#define S0_GPIO_Port GPIOB
#define S1_Pin GPIO_PIN_13
#define S1_GPIO_Port GPIOB
#define S2_Pin GPIO_PIN_14
#define S2_GPIO_Port GPIOB
#define S3_Pin GPIO_PIN_15
#define S3_GPIO_Port GPIOB
#define RED_Pin GPIO_PIN_6
#define RED_GPIO_Port GPIOC
#define GREEN_Pin GPIO_PIN_8
#define GREEN_GPIO_Port GPIOC
#define BLUE_Pin GPIO_PIN_9
#define BLUE_GPIO_Port GPIOC
#define TMS_Pin GPIO_PIN_13
#define TMS_GPIO_Port GPIOA
#define TCK_Pin GPIO_PIN_14
#define TCK_GPIO_Port GPIOA
#define Box_detect_Pin GPIO_PIN_15
#define Box_detect_GPIO_Port GPIOA
#define SWO_Pin GPIO_PIN_3
#define SWO_GPIO_Port GPIOB

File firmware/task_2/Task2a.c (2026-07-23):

// ...existing code...
/*
*
*   ===================================================
*       CropDrop Bot (CB) Theme [eYRC 2025-26]
*   ===================================================
*
*  This script is intended to be an Boilerplate for 
*  Task 2a of CropDrop Bot (CB) Theme [eYRC 2025-26].
*
*  Filename:		Task2a.c
*  Created:		    19/08/2025
*  Last Modified:	12/11/2025
*  Author:		    Mohit,Aaryan,Sanyog
*  Team ID:		    [ CB_4775 ]
*  This software is made available on an "AS IS WHERE IS BASIS".
*  Licensee/end user indemnifies and will keep e-Yantra indemnified from
*  any and all claim(s) that emanate from the use of the Software or
*  breach of the terms of this agreement.
*  
*  e-Yantra - An MHRD project under National Mission on Education using ICT (NMEICT)
*
**********************************************

*/
// Platform-specific includes for Windows compatibility
#ifdef _WIN32
    #define WINVER 0x0600
    #define _WIN32_WINNT 0x0600
    #include <winsock2.h>
    #include <ws2tcpip.h>
#endif

#include "coppeliasim_client.h"  // Include our header
#include <sys/time.h>
#include <math.h>
#include <string.h>
#include <stdio.h>

// Global client instance for socket communication
SocketClient client;

// ----------------------
// Forward declarations
// ----------------------
void* control_loop(void* arg);

/**
 * @brief Establishes connection to the CoppeliaSim server
 */
int connect_to_server(SocketClient* c, const char* ip, int port) {
#ifdef _WIN32
    // Initialize Winsock on Windows
    WSADATA wsa;
    if (WSAStartup(MAKEWORD(2, 2), &wsa) != 0) {
        printf("WSAStartup failed\n");
        return 0;
    }
#endif
    
    // Create TCP socket
    c->sock = socket(AF_INET, SOCK_STREAM, 0);
    if (c->sock < 0) {
        printf("Socket creation failed\n");
        return 0;
    }

    // Setup server address structure
    struct sockaddr_in serv_addr;
    memset(&serv_addr, 0, sizeof(serv_addr));
    serv_addr.sin_family = AF_INET;
    serv_addr.sin_port = htons(port);
    inet_pton(AF_INET, ip, &serv_addr.sin_addr);

    // Attempt to connect to server
    if (connect(c->sock, (struct sockaddr*)&serv_addr, sizeof(serv_addr)) < 0) {
        printf("Connection failed\n");
        CLOSESOCKET(c->sock);
#ifdef _WIN32
        WSACleanup();
#endif
        return 0;
    }

    c->running = true;

    // Start the receive thread to handle incoming sensor data
#ifdef _WIN32
    c->recv_thread = CreateThread(NULL, 0, (LPTHREAD_START_ROUTINE)receive_loop, c, 0, NULL);
#else
    pthread_create(&c->recv_thread, NULL, receive_loop, c);
#endif

    return 1;
}

/**
 * @brief Get current time in seconds
 */
double get_current_time() {
    struct timeval tv;
    gettimeofday(&tv, NULL);
    return tv.tv_sec + tv.tv_usec / 1000000.0;
}


/**
 * @brief Main control loop thread for robot behavior
 */
void* control_loop(void* arg) {
    SocketClient* c = (SocketClient*)arg;

    // PID params (tune these if needed)
    const float BASE_SPEED = 4.5f;   // base forward speed (left/right)
    const float KP = 8.6f;
    const float KI = 0.001f;
    const float KD = 3.3f;
    const int LOOP_DELAY_MS = 30;    // main loop delay

    // proximity / pick/drop thresholds & timings
    const float PROX_DETECT = 0.35f; // detection distance (m)
    const float PROX_GRIP   = 0.10f; // gripping distance (m)
    const float NODE_SUM_THRESH = 3.4f; // sum of inverted sensors at junction
    const float NODE_SUM_CLEAR = 1.2f;  // require sum to drop below this to clear a junction
    const int TURN_MS = 600;
    const int FORWARD_MS = 1100;
    const float TURN_SPEED = 4.7f;
    const float FORWARD_SPEED = 1.4f;
    const float APPROACH_SPEED = 0.5f;

    // Simulator reports blue in color_r and red in color_b, set to 1 to swap R<->B
    const int COLOR_SWAP_RB = 1; // 0 = no swap, 1 = swap R and G channels
    const int COLOR_SWAP_RG = 1;
    const int COLOR_SWAP_BG = 0;

    float previous_error = 0.0f;
    float integral = 0.0f;
    bool pause_pid = false;   // when true, PID won't send motor commands
    bool carrying = false;
    char carried_color[16] = "none";

    // routing state: 0 = waiting for first junction, 1 = first junction passed; drop at next
    int routing_stage = 0;

    // ignore junctions until this time (seconds) after pickup/turn so we don't re-detect same node
    double node_skip_until = 0.0;

    // debounce for junction detection (avoid immediate re-detect)
    bool junction_active = false;

    // scales for safer line-follow while carrying
    const float CARRY_SPEED_SCALE = 0.85f;
    const float CARRY_CORR_SCALE = 0.50f;

    while (c->running) {
        // Read raw sensors (0..1). For black-line the line is darker -> smaller value,
        // so invert so line => large value (1.0)
        float s0 = c->line_sensors[0];
        float s1 = c->line_sensors[1];
        float s2 = c->line_sensors[2];
        float s3 = c->line_sensors[3];
        float s4 = c->line_sensors[4];

        float lc = 1.0f - s0;
        float l  = 1.0f - s1;
        float m  = 1.0f - s2;
        float r  = 1.0f - s3;
        float rc = 1.0f - s4;

        // Debug occasionally
        static int dbg_count = 0;
        if ((++dbg_count % 200) == 0) {
            printf("LINE RAW: [%.3f %.3f %.3f %.3f %.3f] (inv) prox=%.3f carrying=%d routing_stage=%d\n",
                   s0,s1,s2,s3,s4, c->proximity_distance, carrying, routing_stage);
        }

        // -------------------------
        // PID controller (apply reduced aggressiveness while carrying)
        // -------------------------
        float numerator = (-2.0f * lc) + (-1.0f * l) + (0.0f * m) + (1.0f * r) + (2.0f * rc);
        float denominator = lc + l + m + r + rc;
        float error = 0.0f;
        if (denominator > 0.001f) error = numerator / denominator;

        integral += error;
        float derivative = error - previous_error;
        float correction = (KP * error) + (KI * integral) + (KD * derivative);
        previous_error = error;

        // Apply scaling when carrying to reduce oscillation
        float speed_scale = carrying ? CARRY_SPEED_SCALE : 1.0f;
        float corr_scale = carrying ? CARRY_CORR_SCALE : 1.0f;

        float left_speed = BASE_SPEED * speed_scale + correction * corr_scale;
        float right_speed = BASE_SPEED * speed_scale - correction * corr_scale;

        // Clamp speeds to reasonable range (non-negative forward)
        const float MAX_SPEED = 2.8f;
        if (left_speed < 0.0f) left_speed = 0.0f;
        if (right_speed < 0.0f) right_speed = 0.0f;
        if (left_speed > MAX_SPEED) left_speed = MAX_SPEED;
        if (right_speed > MAX_SPEED) right_speed = MAX_SPEED;

        // Only send PID motor commands when not paused for pickup/routing
        if (!pause_pid) {
            set_motor(c, left_speed, right_speed);
        } else {
            // keep motors stopped while paused
            set_motor(c, 0.0f, 0.0f);
        }
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

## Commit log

2026-07-23 Add firmware documentation to README.md
    Added detailed documentation about the firmware for the STM32 F103RB microcontroller, including core features, directory structure, and build instructions.
2026-07-23 Update README with image links for setup and assembly

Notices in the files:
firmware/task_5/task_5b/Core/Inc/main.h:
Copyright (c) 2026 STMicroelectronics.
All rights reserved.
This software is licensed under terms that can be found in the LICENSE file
